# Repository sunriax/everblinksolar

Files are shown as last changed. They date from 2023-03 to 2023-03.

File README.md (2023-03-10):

    

# Everblink Solar

The Everblink Solar is a simple electronic circuit for beginner. The circuit can be solderd on a strip grid board and needs no Battery

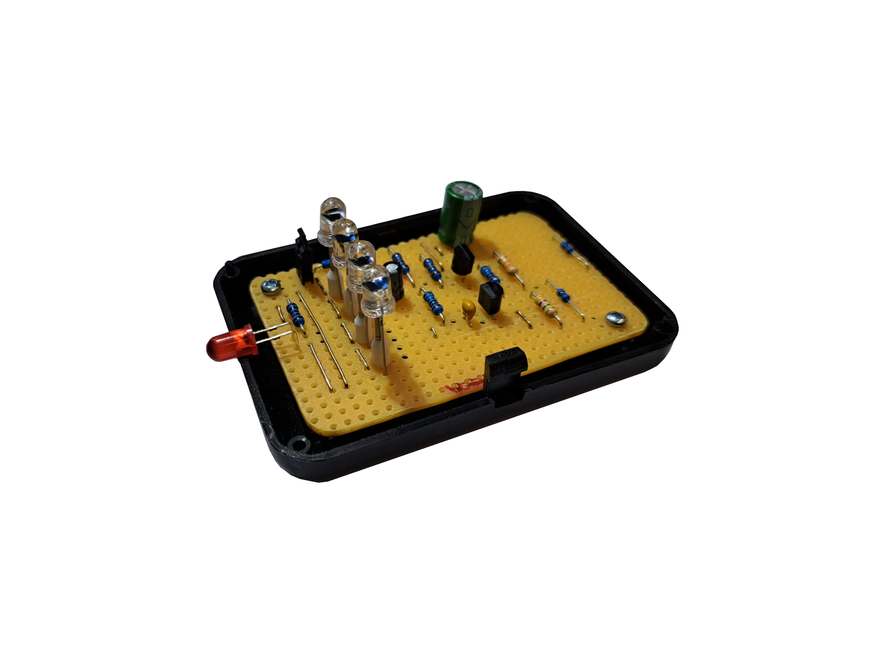
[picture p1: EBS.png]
Everblink Solar


# Data

* [Manufacturing Data](./EBS.pdf)
* [Schematic](./Schematic.pdf)
* [Lochmaster Layout Top](./LM_Top.pdf)
* [Lochmaster Layout Bottom](./LM_Bottom.pdf)

---

R. GAECHTER

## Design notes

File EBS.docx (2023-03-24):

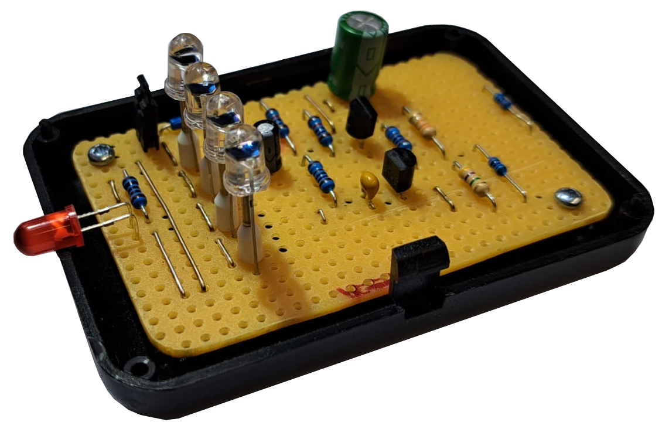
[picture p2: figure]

# 1. Aufgabenstellung

Gemäß den Fertigungsunterlagen ist das Ewigblink Solar zu bestücken, löten und in Betrieb zu nehmen. Das Gehäuse ist dabei mechanisch zu bearbeiten. An der funktionierenden Schaltung sind die im Kapitel 6 (Inbetriebnahme und Messtechnik) angeführten Messungen durchzuführen.

Hinweise zum Aufbau der Schaltung:

1) Lochreihen horizontal und vertikal der Leiterplatte kontrollieren; Kontrollpunkt für Zählrichtung setzen und Bohrungen durchführen.!
2) Gemäß Plan mit Trennwerkzeug die Unterbrechungen herstellen; anschließend die abstehenden Kupfergrate mit feinem Schleifpapier entfernen und die Kanten rund schleifen.
3) Brücken aus blankem Brückendraht mittels Biegelehre oder Spitzzange herstellen und einlöten.
4) Widerstände mit Biegelehre oder Spitzzange auf das entsprechende Rastermaß biegen und einlöten.
5) Transistoren auf das entsprechende Rastermaß biegen und einlöten.
6) Kondensatoren einlöten
7) Photodioden mit 13,5mm Abstand einlöten
8) Kontrolle auf richtige Bestückung der Bauteile, auf saubere Lötstellen und eventuell vorhandene Kurzschlüsse zwischen den Leiterbahnen
9) Mit akustischem Durchgangsprüfer (Multimeter) anhand des Schaltplans alle Verbindungen kontrollieren.
10) Gemäß Plan das Gehäuse bearbeiten.
11) Inbetriebnahme und Messungen durchführen.

# 2. Schaltplan

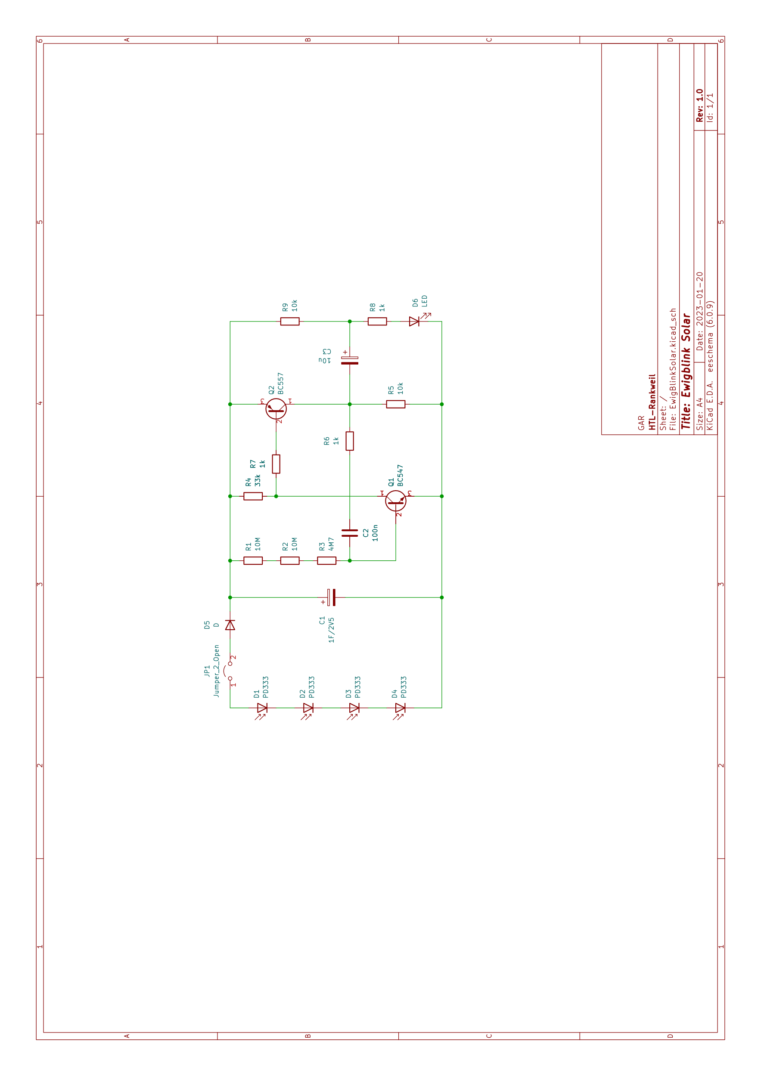
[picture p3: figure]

# 1. Bestückungsplan

## Ansicht Platine von oben:

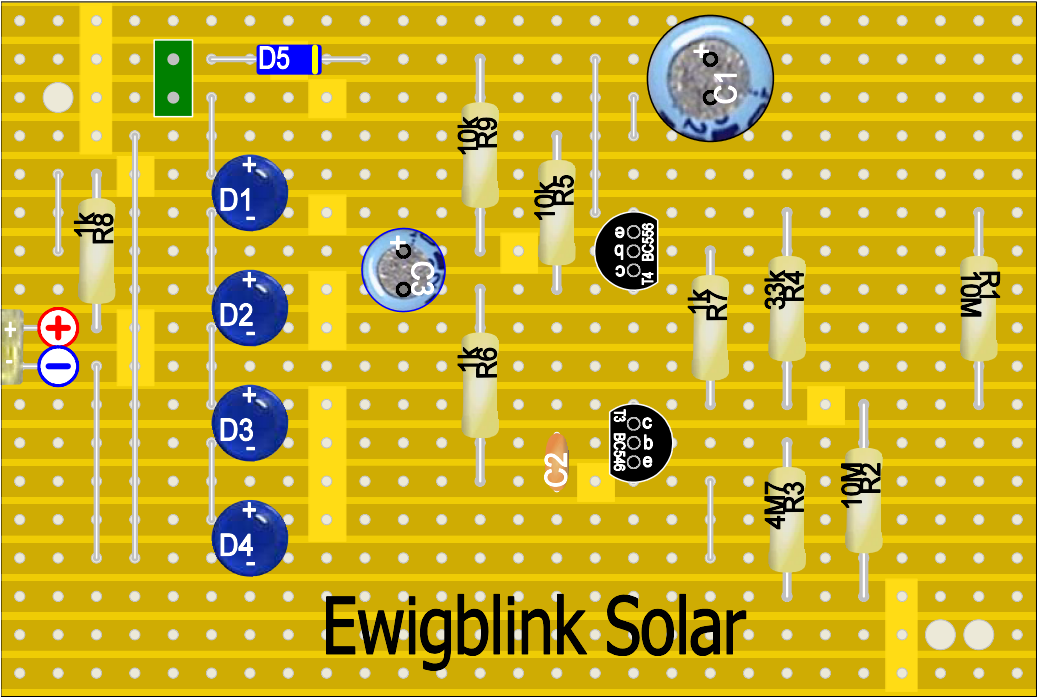
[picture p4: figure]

## Ansicht Platine gewendet:

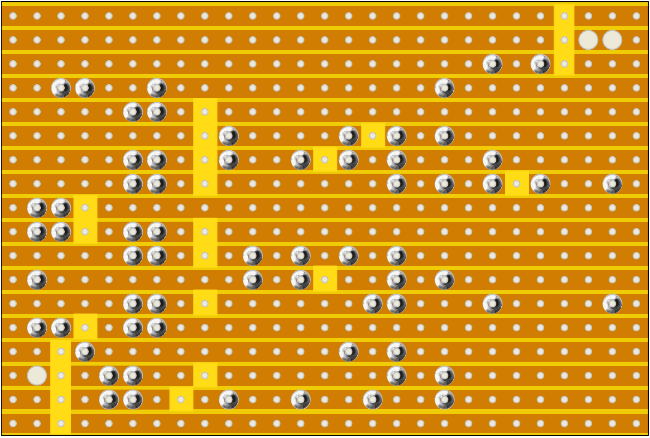
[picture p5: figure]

⌀2,1mm

⌀2,1mm

# 3. Stückliste

Pos. | Teil | Stück | Bezeichnung | Lieferant | Preis
1 | - | 1 | Streifenrasterplatine 70x47mm | HTL
2 | D1-D4 | 4 | Fotodiode PD333 | HTL
3 | LED6 | 1 | Leuchtdiode 5mm Rot oder Gelb | HTL
4 | C1 | 1 | SuperElko 1F/2V5 | HTL
5 | C2 | 1 | Kondensator 100nF | HTL
6 | C3 | 1 | Elko 10µF/16V | HTL
7 | R1-R2 | 2 | THT Widerstand 10MΩ | HTL
8 | R3 | 1 | THT Widerstand 4,7MΩ | HTL
9 | R4 | 1 | THT Widerstand 33kΩ | HTL
10 | R5 | 1 | THT Widerstand 10kΩ | HTL
11 | R6-R8 | 2 | THT Widerstand 1kΩ | HTL
12 | R9 | 1 | THT Widerstand 10kΩ | HTL
13 | JP1 | 1 | Stiftleiste 2x2,54 | HTL
14 | - | 4 | Blechschrauben | HTL
15 | - | 1 | Gehäuse 80,5x56 | HTL
16 | - | 1 | Jumper | HTL
17 | - | 4 | Aderendhülse 0,25 (Violett) | HTL

# 4. Bohrplan

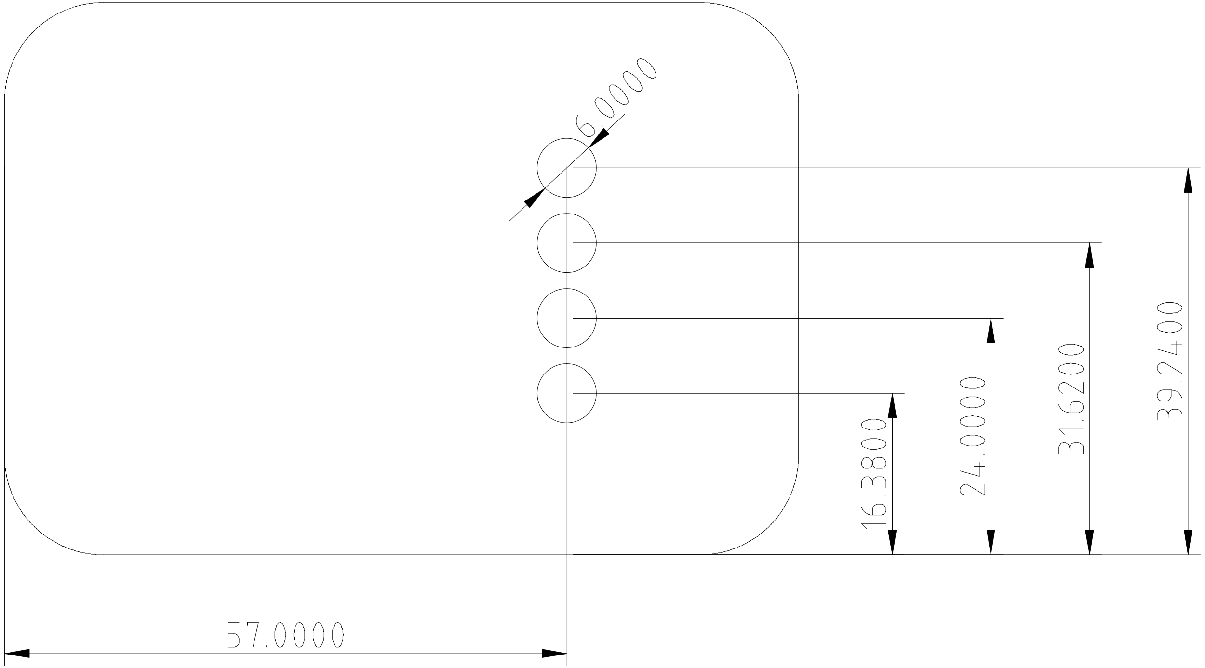
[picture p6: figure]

# 5. Schaltungsbeschreibung

Durch die Einstrahlung von Sonnenlicht wird in den Fotodioden eine Spannung induziert, die den Superkondensator auflädt. Ab einer gewissen Spannung fangen die Transistoren der Schaltung, angeregt durch Bauteiltoleranzen, hin und her zu schalten. Dadurch blinkt die LED immer wieder kurz auf

# 6. Inbetriebnahme und Messtechnik

- Der Kondensator ist über JP1 und GND auf 2,2V aufzuladen

- Der Jumper JP1 ist zu schließen

- Die Spannung am Vorwiderstand R8 der LED ist zu messen

- Der Strom durch die Leuchtdiode ist zu ermitteln

- Die Stromaufnahme der Gesamtschaltung ist mit einem speziellen Multimeter (Lehrer) zu messen! Zeichne die dazugehörige Messschaltung!

Messchaltung:

Messwert Iges: ___________mA

Messwert UR8:___________V

Berechnung:

Rechenwert ILED: ___________mA

# 7. Beurteilung:

Gesamtpunktezahl 100P

Fertigung: 50P/____

Trennungen 20P/____

Bestückung 10P/____

Lötstellen 10P/____

Gehäuse 10P/____

Inbetriebnahme: 20P/____

Messungen: 30P/____

Spannung/Strom am Vorwiderstand

Messergebnisse: 10P/____

Gesamtstromaufnahme

Messergebnisse: 10P/____

Messschaltung 10P/____

Punkteabzug:

Fertigung: Je ein Punkt Abzug für falsch gesetzte Trennung oder unzureichende Trennung; Bestückungsfehler; unsauber bestückte Brücken und Bauteile; kalte Lötstelle oder Kurzschluss durch Löten.

Je 0,5 P Abzug für unsaubere Lötstellen.

Inbetriebnahme: volle Punktezahl für selbständige Inbetriebnahme mit einwandfreier Funktion; halbe Punktezahl für Inbetriebnahme mit Hilfestellung des Lehrers; keine Punkte für Inbetriebnahme durch den Lehrer.

Messungen: keine Punkte für falsche Messergebnisse; 2 P Abzug je Fehler in der Dokumentation (falsche Symbole oder Verbindungsfehler in der Messschaltung, falsche Einheiten und Beschriftungen usw.)

Punkteverteilung:

00P bis 50P nicht genügend (5)

51P bis 65P genügend (4)

66P bis 78P befriedigend (3)

79P bis 90P gut (2)

91P bis 100P sehr gut (1)

Punktezahl erreicht: ___________ Note: _______

Name: Seite 1 Datum:

ELDE / 1AFEL Fertigungsunterlagen Ewigblink Solar

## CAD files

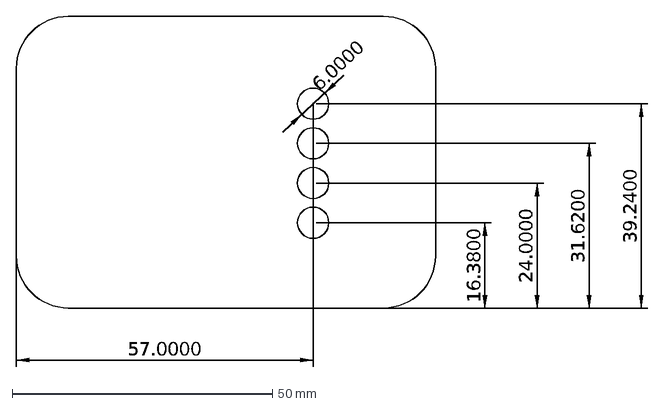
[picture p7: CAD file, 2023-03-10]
Case.dxf
57.0000
31.6200
24.0000
16.3800
39.2400
6.0000

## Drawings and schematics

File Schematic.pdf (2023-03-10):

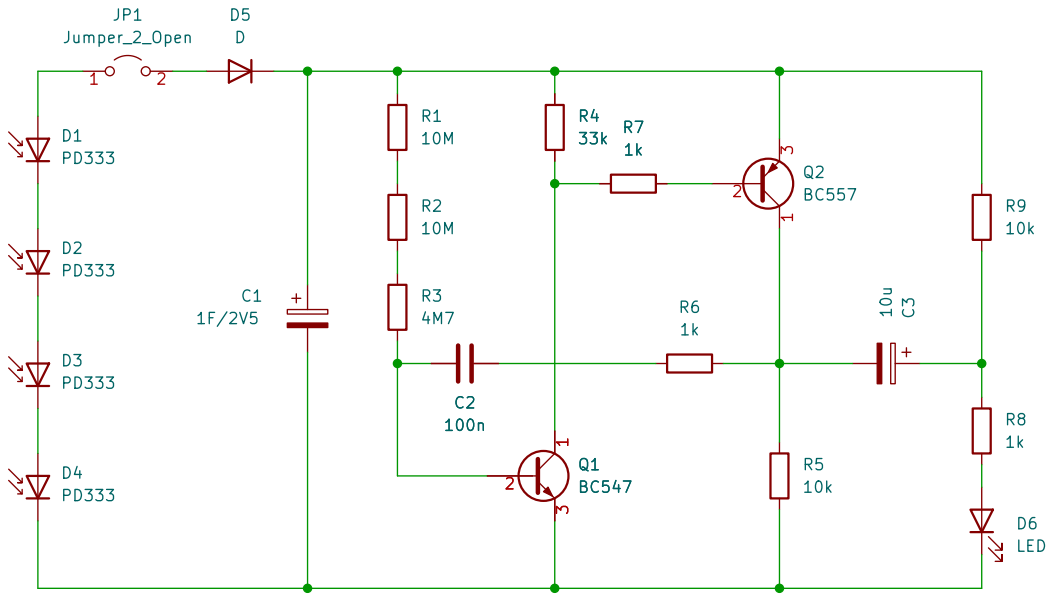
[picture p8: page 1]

File: EwigBlinkSolar.kicad_sch Sheet: / HTL-Rankweil GAR

Id: 1/1 Title: Ewigblink Solar

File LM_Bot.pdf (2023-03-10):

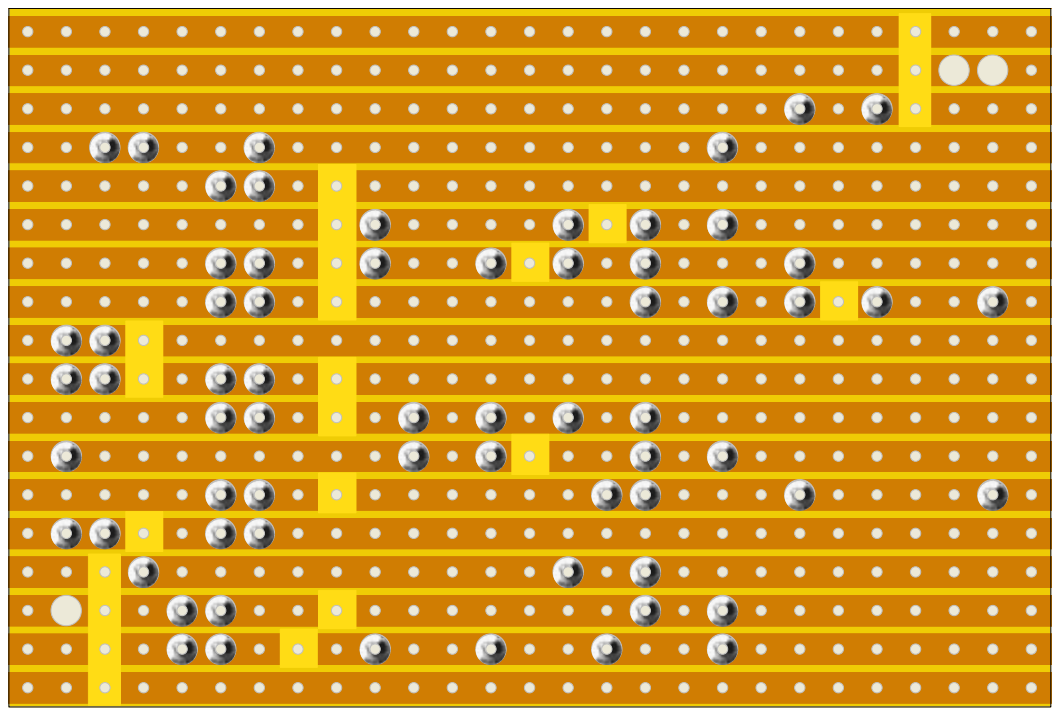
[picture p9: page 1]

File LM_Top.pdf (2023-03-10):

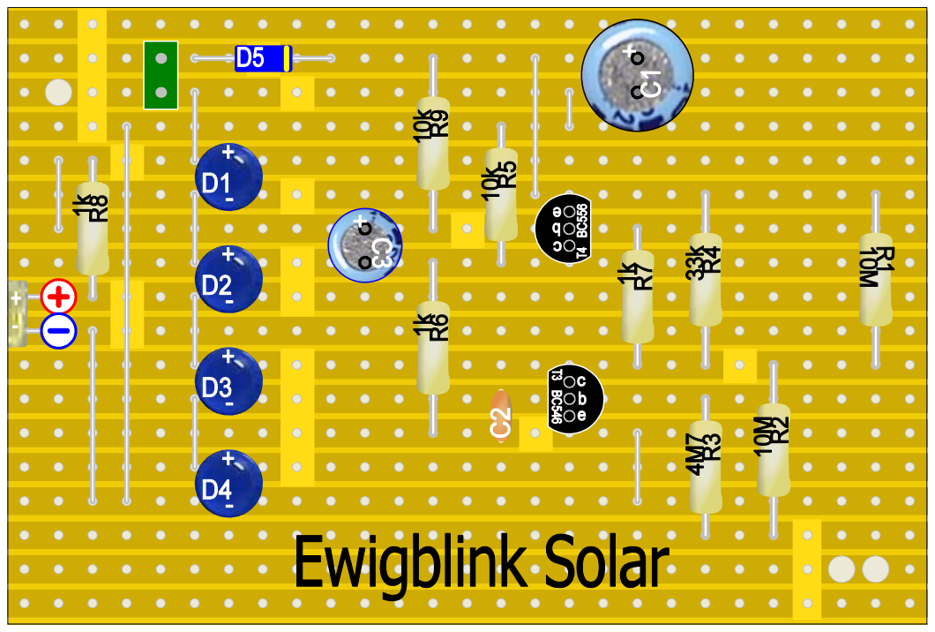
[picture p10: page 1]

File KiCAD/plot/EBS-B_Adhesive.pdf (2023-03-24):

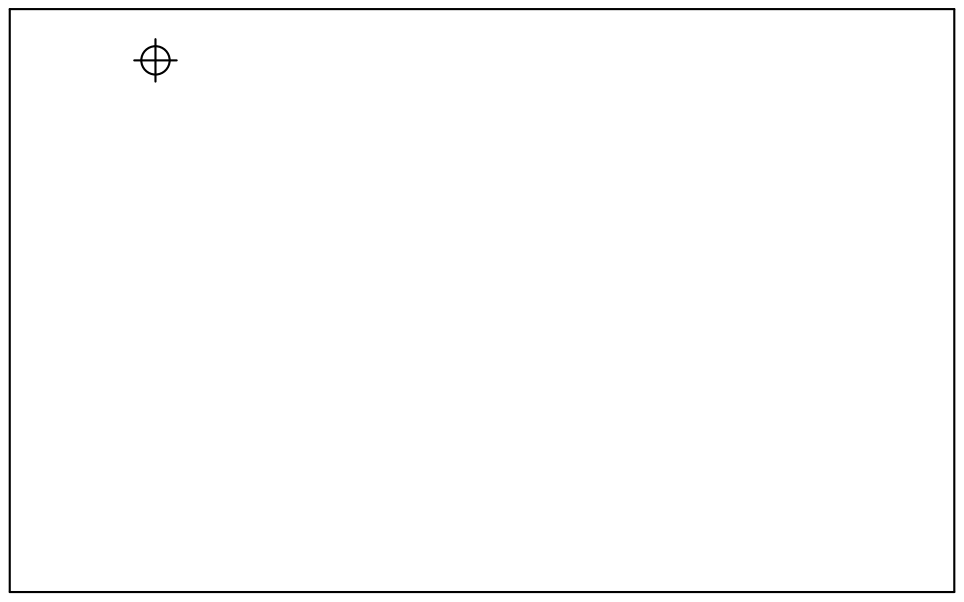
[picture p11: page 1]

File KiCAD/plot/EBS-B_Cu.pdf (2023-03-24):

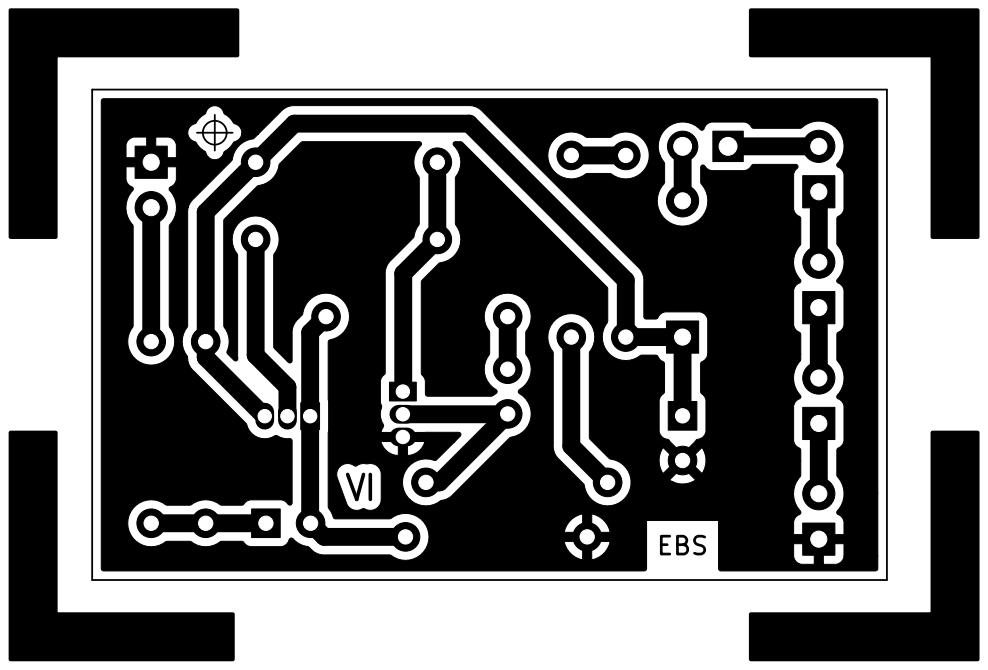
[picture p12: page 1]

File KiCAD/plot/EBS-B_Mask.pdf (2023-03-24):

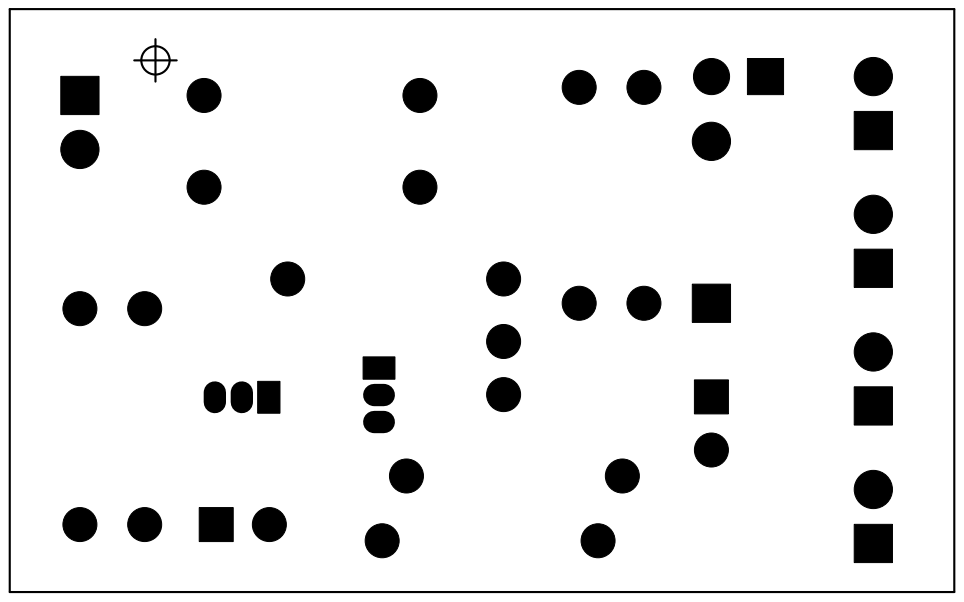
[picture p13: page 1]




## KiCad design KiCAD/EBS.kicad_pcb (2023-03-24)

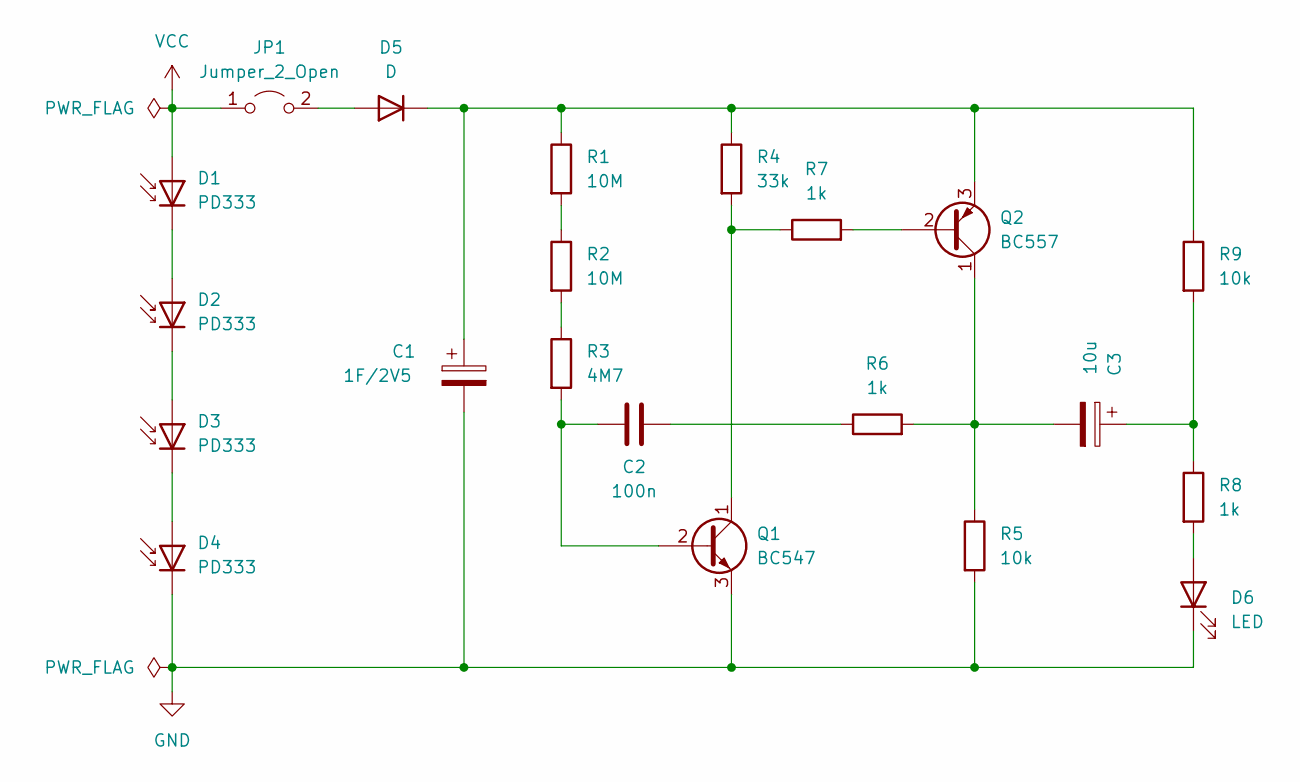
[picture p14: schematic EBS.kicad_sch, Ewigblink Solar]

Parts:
C1: 1F/2V5; CP_Radial_D6.3mm_P2.50mm
C2: 100n; C_Disc_D3.8mm_W2.6mm_P2.50mm
C3: 10u; CP_Radial_D5.0mm_P2.50mm
D1, D2, D3, D4: PD333; LED_D5.0mm
D5: D; D_A-405_P7.62mm_Horizontal
D6: LED; LED_D5.0mm
JP1: Jumper_2_Open; PinHeader_1x02_P2.54mm_Vertical
Q1: BC547; TO-92_Inline
Q2: BC557; TO-92_Inline
R1, R2: 10M; R_Axial_DIN0207_L6.3mm_D2.5mm_P10.16mm_Horizontal
R3: 4M7; R_Axial_DIN0207_L6.3mm_D2.5mm_P10.16mm_Horizontal
R4: 33k; R_Axial_DIN0207_L6.3mm_D2.5mm_P10.16mm_Horizontal
R5, R9: 10k; R_Axial_DIN0207_L6.3mm_D2.5mm_P10.16mm_Horizontal
R6, R7, R8: 1k; R_Axial_DIN0207_L6.3mm_D2.5mm_P10.16mm_Horizontal

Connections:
GND: C1.2, D4.1 (K), D6.1 (K), Q1.3 (E), R5.2
unnamed: C1.1, D5.1 (K), Q2.3 (E), R1.1, R4.1, R9.1
unnamed: C2.1, Q1.2 (B), R3.2
unnamed: C2.2, R6.1
unnamed: C3.1, R8.1, R9.2
unnamed: C3.2, Q2.1 (C), R5.1, R6.2
unnamed: D1.1 (K), D2.2 (A)
unnamed: D2.1 (K), D3.2 (A)
unnamed: D3.1 (K), D4.2 (A)
unnamed: D5.2 (A), JP1.2 (B)
unnamed: D6.2 (A), R8.2
unnamed: Q1.1 (C), R4.2, R7.1
unnamed: Q2.2 (B), R7.2
unnamed: R1.2, R2.1
unnamed: R2.2, R3.1
VCC: D1.2 (A), JP1.1 (A)

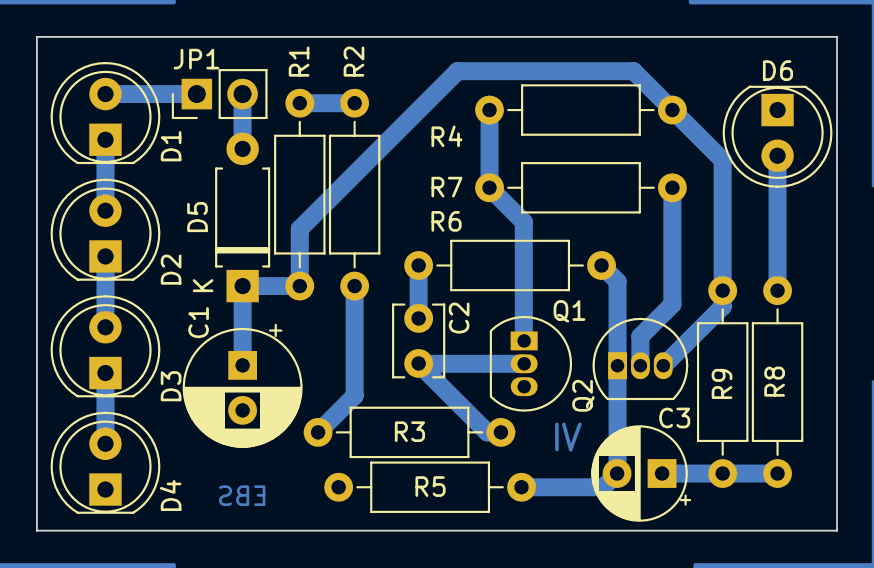
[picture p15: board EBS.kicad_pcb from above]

Board: 2 copper layers, 44.4 x 27.4 mm, 21 parts (0 on the bottom side), 16 nets.

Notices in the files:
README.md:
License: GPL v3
